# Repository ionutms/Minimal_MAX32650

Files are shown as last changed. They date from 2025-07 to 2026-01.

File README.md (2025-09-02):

# Minimal_MAX32650

## Overview

This repository contains a minimal KiCad design project for the Analog Devices MAX32650, an ultra-low-power microcontroller unit (MCU) designed for high-performance, battery-powered applications. It is part of the DARWIN family of MCUs, which are built to handle complex applications in the evolving Internet of Things (IoT) landscape.

## Disclaimer

> [!NOTE]
> This project is provided "as is" and without any warranty, express or implied. For more details, please see the [LICENSE](LICENSE) file.

## About the MAX32650

The MAX32650 from Analog Devices is an ultra-low-power microcontroller unit (MCU) designed for high-performance, battery-powered applications. It is part of the DARWIN family of MCUs, which are built to handle complex applications in the evolving Internet of Things (IoT) landscape.

Key features include:

- **Processor:** It uses an Arm® Cortex®-M4 processor with a Floating Point Unit (FPU) that can run at a core speed of 120MHz.
- **Memory:** The MCU is equipped with 3MB of internal Flash memory and 1MB of internal SRAM. It also supports memory scalability through multiple memory-expansion interfaces.
- **Power Consumption:** It is designed for low power consumption, with a rating of 104µW/MHz when executing from cache at 1.1V. It features five low-power modes to control the clock, peripherals, and voltage.
- **Peripherals and Interfaces:** The MAX32650 includes a variety of interfaces, such as a USB 2.0 Full-Speed Device Interface, a Micro-SD Card Interface, and up to 105 General-Purpose I/O (GPIO) pins. It also has a SmartDMA feature that performs complex background processing to reduce overall power consumption.
- **Secure Versions:** A secure version, the MAX32651, is available with a trust protection unit (TPU) that provides features like an AES engine, a secure bootloader, and on-the-fly data decryption.

## Project Structure

```
minimal_max32650/
├── minimal_max32650.kicad_sch       # Main schematic file
├── minimal_max32650.kicad_pcb       # PCB layout file
├── minimal_max32650.kicad_pro       # Project configuration file
├── fp-lib-table                     # Footprint library table
├── sym-lib-table                    # Symbol library table
├── project_jobs_set.kicad_jobset    # Project job settings
├── ibom.config.ini                  # Interactive BOM configuration
├── docs/                            # Documentation files
│   ├── pictures/                    # Images and photos
│   ├── schematics/                  # Schematic PDF exports
│   └── 3d_models/                   # 3D model files
└── KiCAD_Symbols_Generator/         # Submodule for symbol generation from CSV data
```

## Project Features

This design provides a minimal implementation of the MAX32650 with the following features:

- **Power Supply:**
  - VIN: +3.3V
- **Bill of Materials (BOM):**
  - Interactive HTML BOM (`ibom.html`) for easy component identification and sourcing.
- **Libraries:**
  - Comprehensive symbol and footprint libraries integrated as a submodule.
- **3D Model:**
  - Includes a 3D model of the board for better visualization.

## Getting Started

### Prerequisites

- [KiCad EDA](https://www.kicad.org/) version 9.0 or later installed on your system
- Git (for cloning the repository and submodule management)

### Opening the Project

1. **Clone the repository** (including submodules):
   ```bash
   git clone --recursive https://github.com/ionutms/Minimal_MAX32650.git
   ```
   
   If you've already cloned the repository without submodules, initialize them with:
   ```bash
   git submodule init
   git submodule update
   ```

2. **Open the project in KiCad**:
   - Launch KiCad
   - Click "Open Existing Project"
   - Navigate to the cloned repository folder
   - Select the `minimal_max32650.kicad_pro` file

3. **Explore the design**:
   - Open the schematic editor to view the circuit design
   - Open the PCB editor to view the board layout
   - Review the symbol and footprint libraries used in the design

### Project Files

- **Main schematic**: `minimal_max32650.kicad_sch` - Contains the primary circuit design with the MAX32650 and support components
- **PCB layout**: `minimal_max32650.kicad_pcb` - Physical board design file with proper component placement
- **Project configuration**: `minimal_max32650.kicad_pro` - KiCad project settings

## Dependencies

This project has the following dependencies:

### 1. KiCAD Symbols Generator

This repository uses [KiCAD_Symbols_Generator](https://github.com/ionutms/KiCAD_Symbols_Generator) as a submodule for custom symbol generation.

To initialize the submodule after cloning this repository:

```bash
git submodule update --init --recursive
```

### 2. 3D Models

This project requires the [3D_Models_Vault](https://github.com/ionutms/3D_Models_Vault) repository for 3D models.

#### Setup for KiCAD 9:

1. Clone the 3D models repository:
   ```bash
   git clone https://github.com/ionutms/3D_Models_Vault.git
   ```

2. In KiCAD 9, add an environment variable:
   - Variable name: `KICAD9_3D_MODELS_VAULT`
   - Variable value: Full path to where you cloned the 3D_Models_Vault repository

## Usage

After setting up the dependencies, open the project in KiCAD 9 to access all features including the 3D models.

## Symbol Generator Submodule

This project includes the KiCAD_Symbols_Generator as a submodule, which provides tools for generating KiCad symbols from CSV data files. For more information on using this tool, see the [KiCAD_Symbols_Generator documentation](minimal_max32650/KiCAD_Symbols_Generator/README.md).

## Documentation

The `docs` folder contains:
- Schematic PDF exports
- Images and photos of the design
- 3D model files (GLB and WRL formats)

## Visuals

The following images showcase the PCB design from different perspectives:

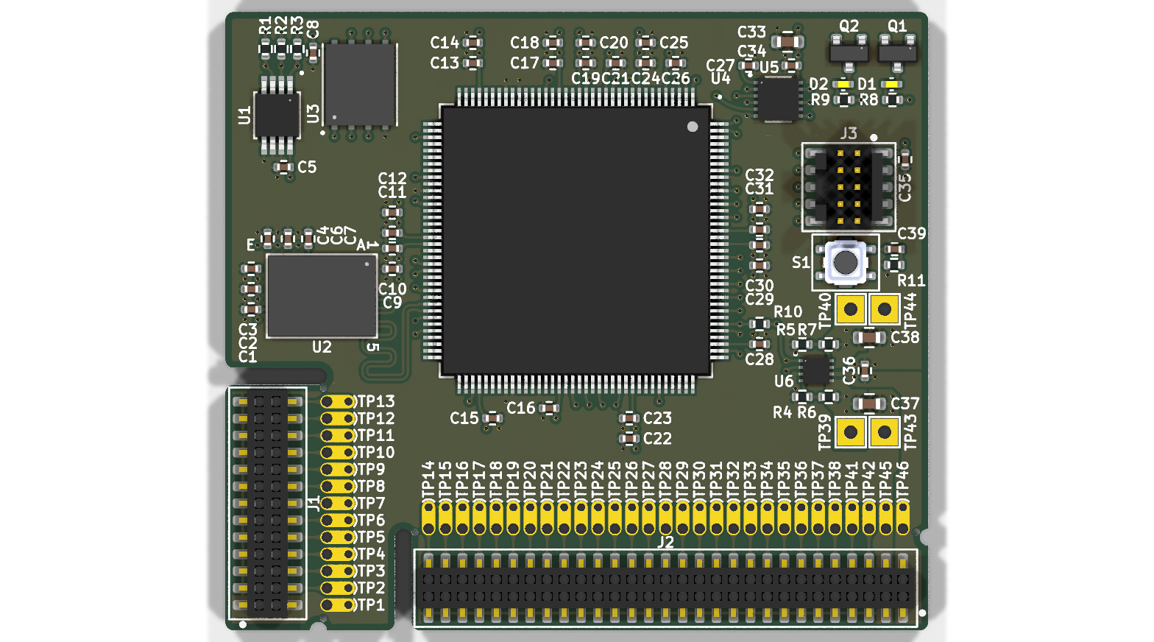
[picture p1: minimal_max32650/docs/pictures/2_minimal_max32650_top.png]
Top View

*Top View of the PCB*

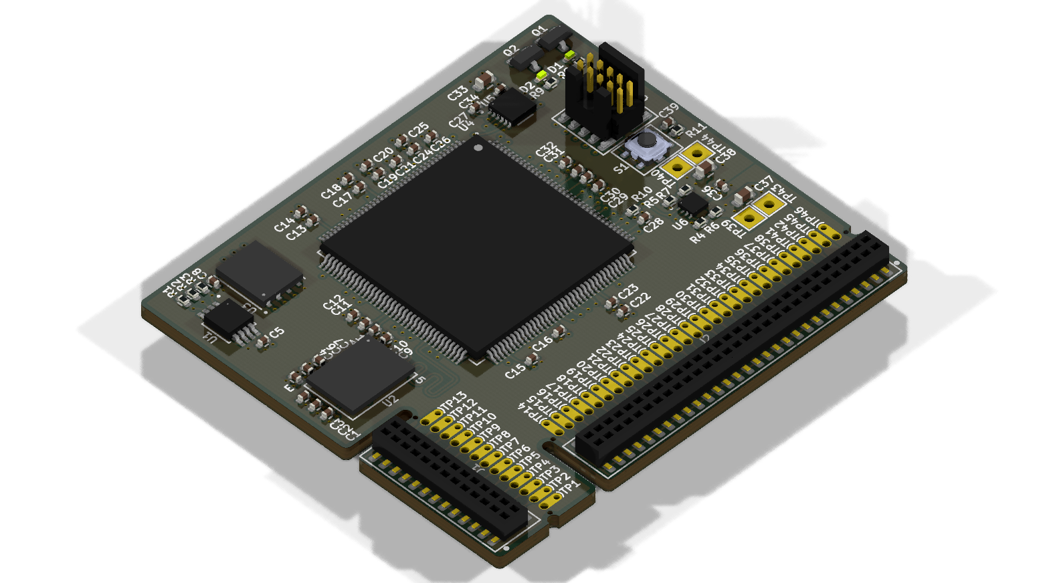
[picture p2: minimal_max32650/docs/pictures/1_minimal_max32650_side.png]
Side View

*Side View of the PCB*

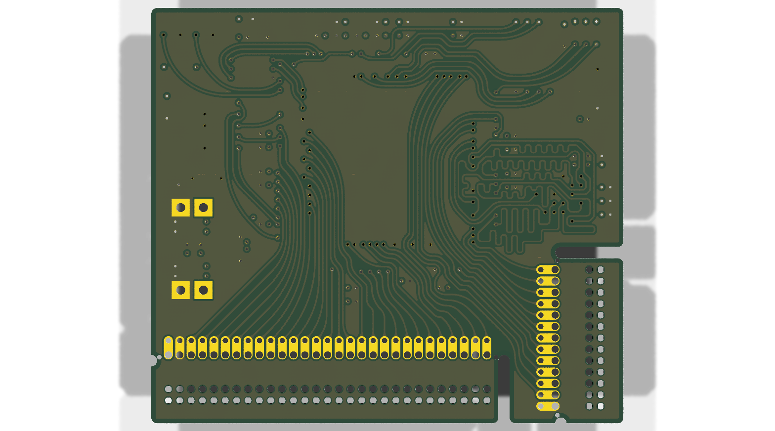
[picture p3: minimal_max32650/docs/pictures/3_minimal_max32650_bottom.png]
Bottom View

*Bottom View of the PCB*

## License

This project is licensed under the MIT License - see the [LICENSE](LICENSE) file for details.

## References

- [MAX32650 Datasheet](https://www.analog.com/media/en/technical-documentation/data-sheets/MAX32650-MAX32651.pdf)
- [KiCad EDA](https://www.kicad.org/)

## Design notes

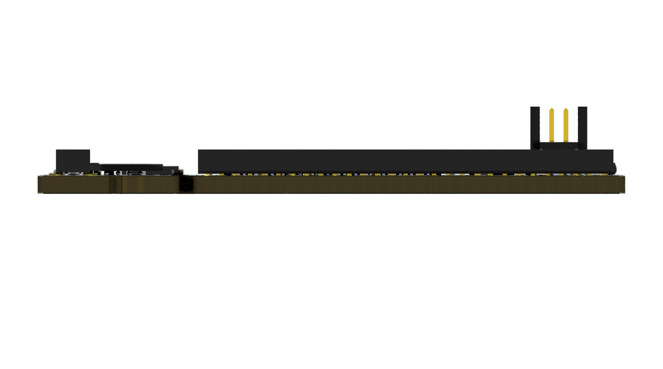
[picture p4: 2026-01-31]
minimal_max32650/docs/pictures/6_minimal_max32650_front.png

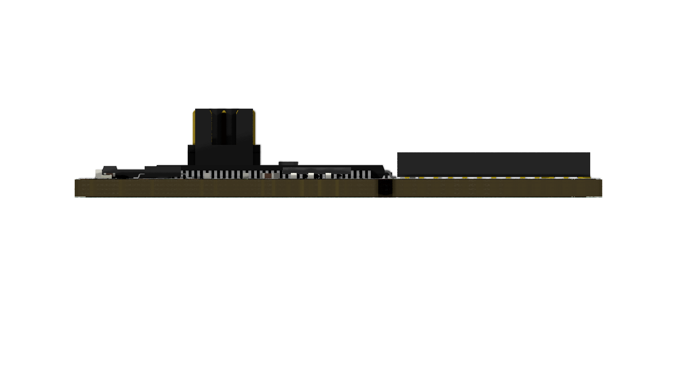
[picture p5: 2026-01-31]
minimal_max32650/docs/pictures/4_minimal_max32650_left.png

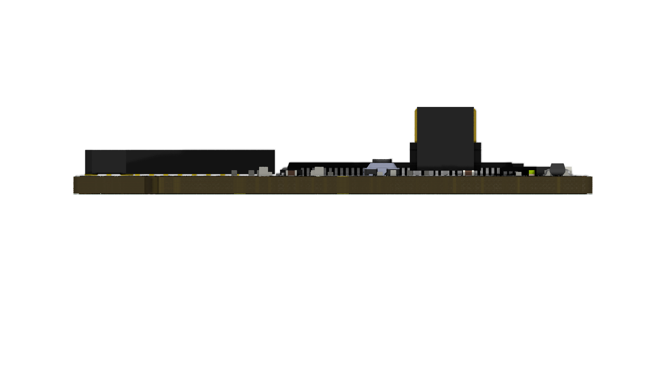
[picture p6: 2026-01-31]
minimal_max32650/docs/pictures/5_minimal_max32650_right.png

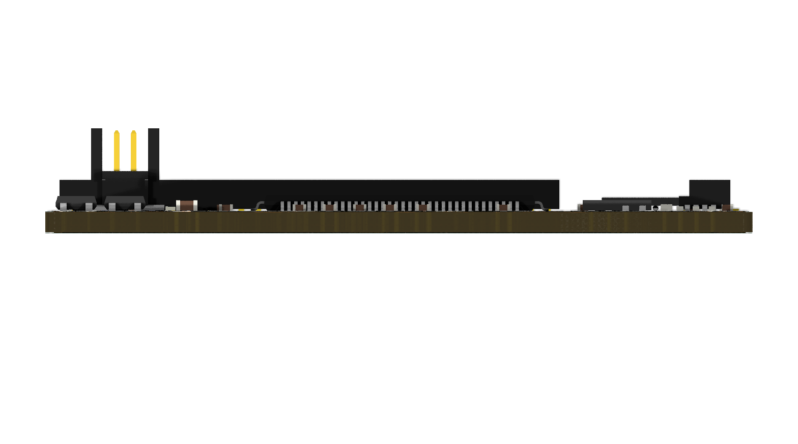
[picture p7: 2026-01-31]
minimal_max32650/docs/pictures/7_minimal_max32650_back.png

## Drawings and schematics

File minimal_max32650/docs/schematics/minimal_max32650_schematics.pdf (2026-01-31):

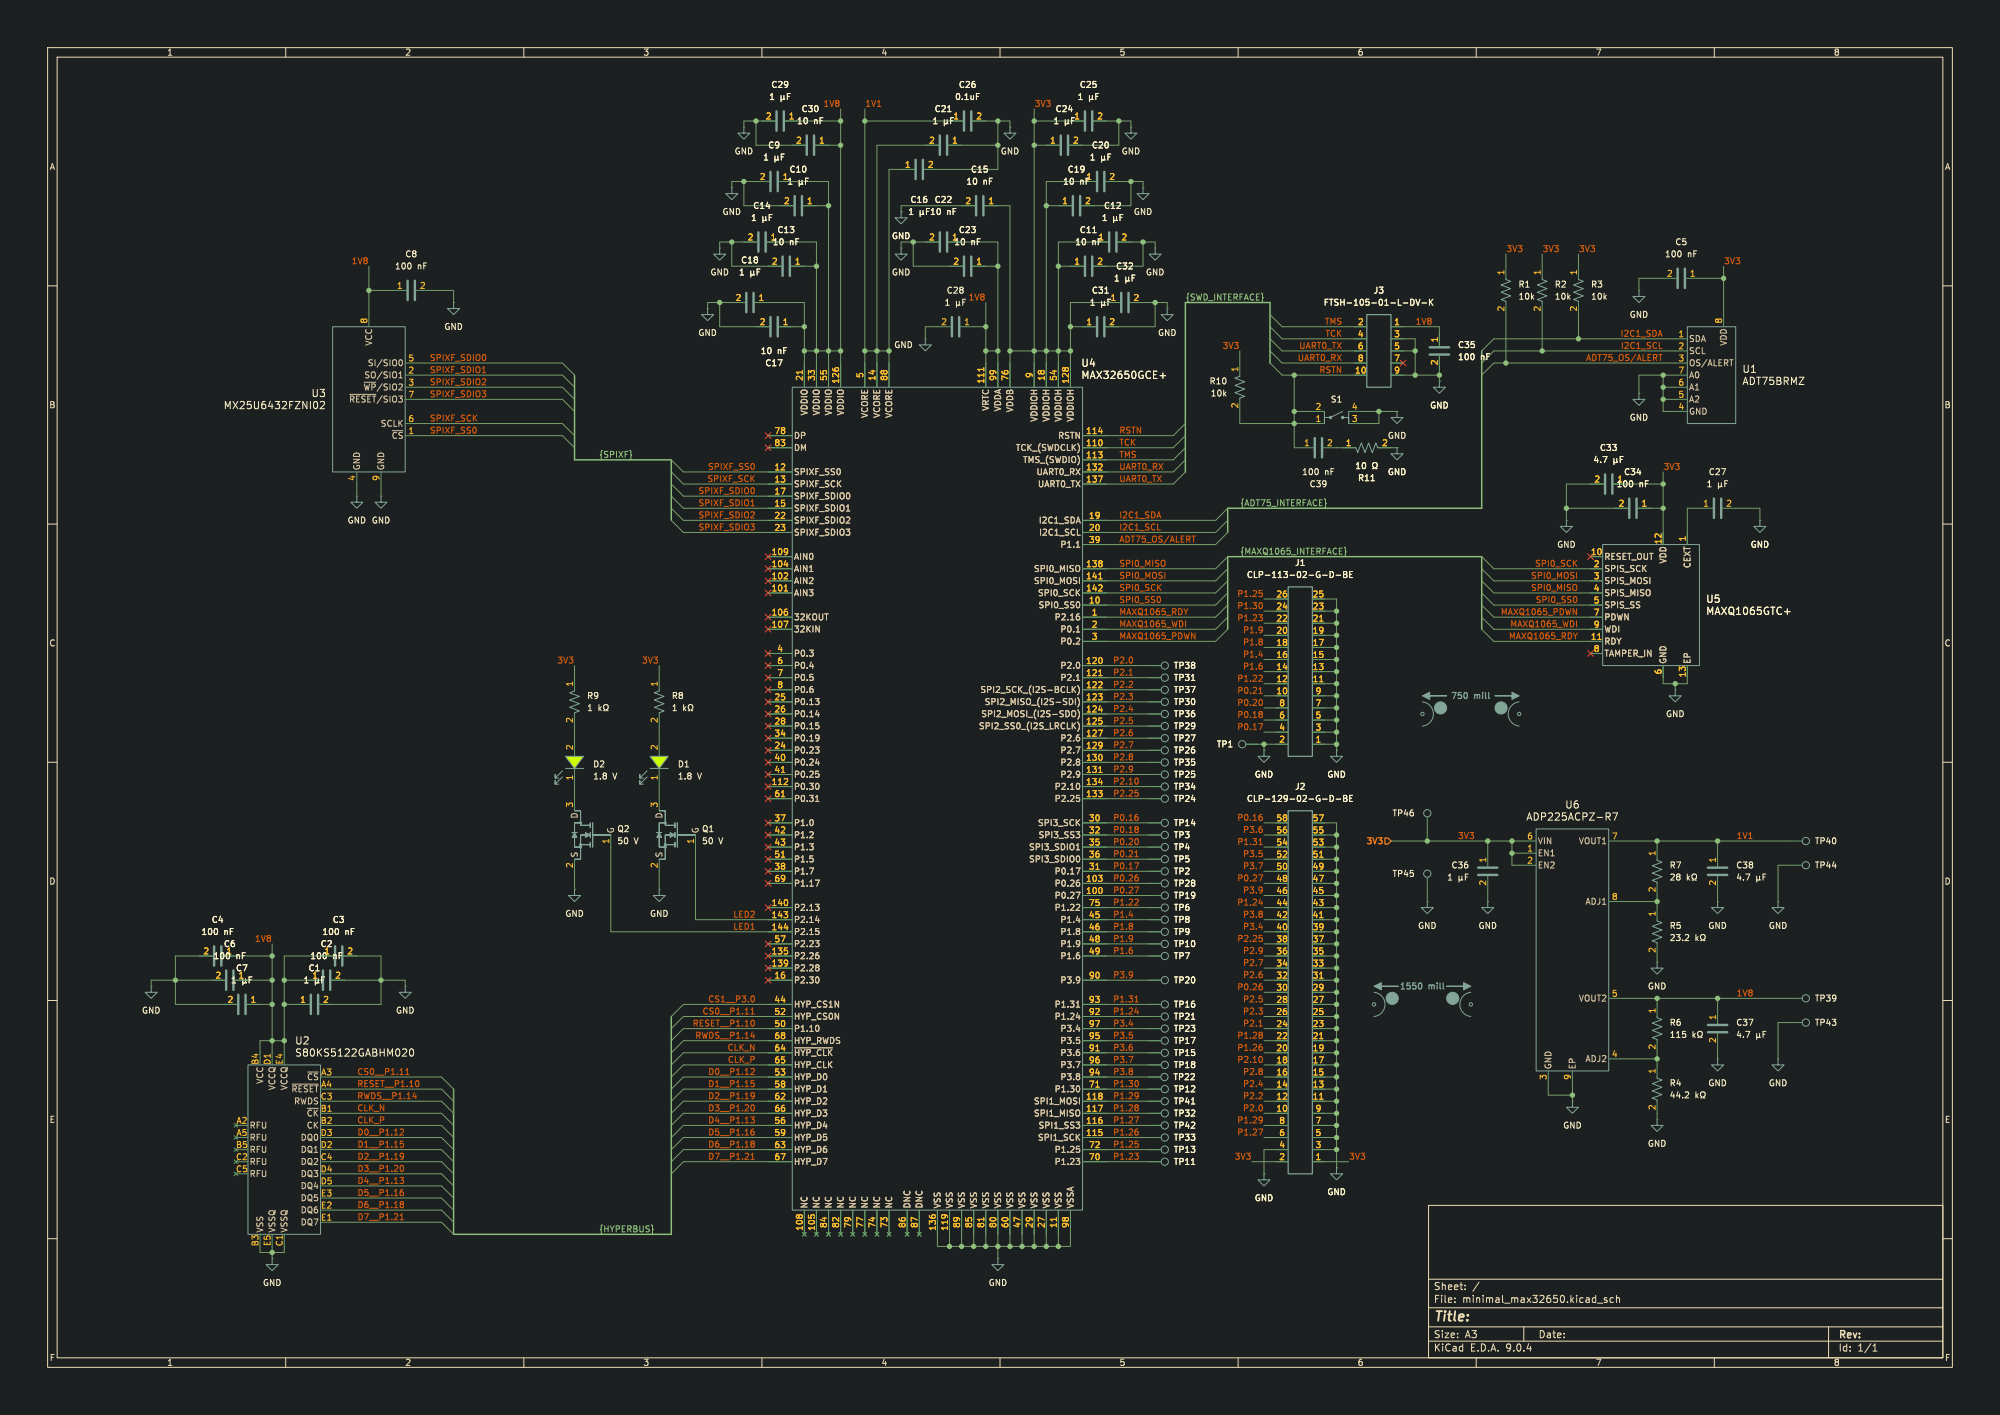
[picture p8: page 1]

9 SI/SIO0 5 SO/SIO1 2 SCLK 6 ~{WP}/SIO23 ~{RESET}/SIO37 ~{CS}1 U3 MX25U6432FZNI02

5 NC 77 VCORE 14 NC 74 VCORE 88 NC 73 DNC 86 DNC 87 VSS 136 VSS 119 VSS 89 VSS 85 VRTC 111 VSS 81 VDDA 99 VSS 80 VDDB 76 VSS 60 VSS 47 VDDIOH

9 VSS 29 VDDIOH 18 VSS 27 VDDIOH 54 VSS 11 VDDIOH 128 VSSA 98 RSTN 114 TCK_(SWDCLK) 110 TMS_(SWDIO) 113 UART0_RX 132 UART0_TX 137

Id: 1/1 Title: File: minimal_max32650.kicad_sch Sheet: /

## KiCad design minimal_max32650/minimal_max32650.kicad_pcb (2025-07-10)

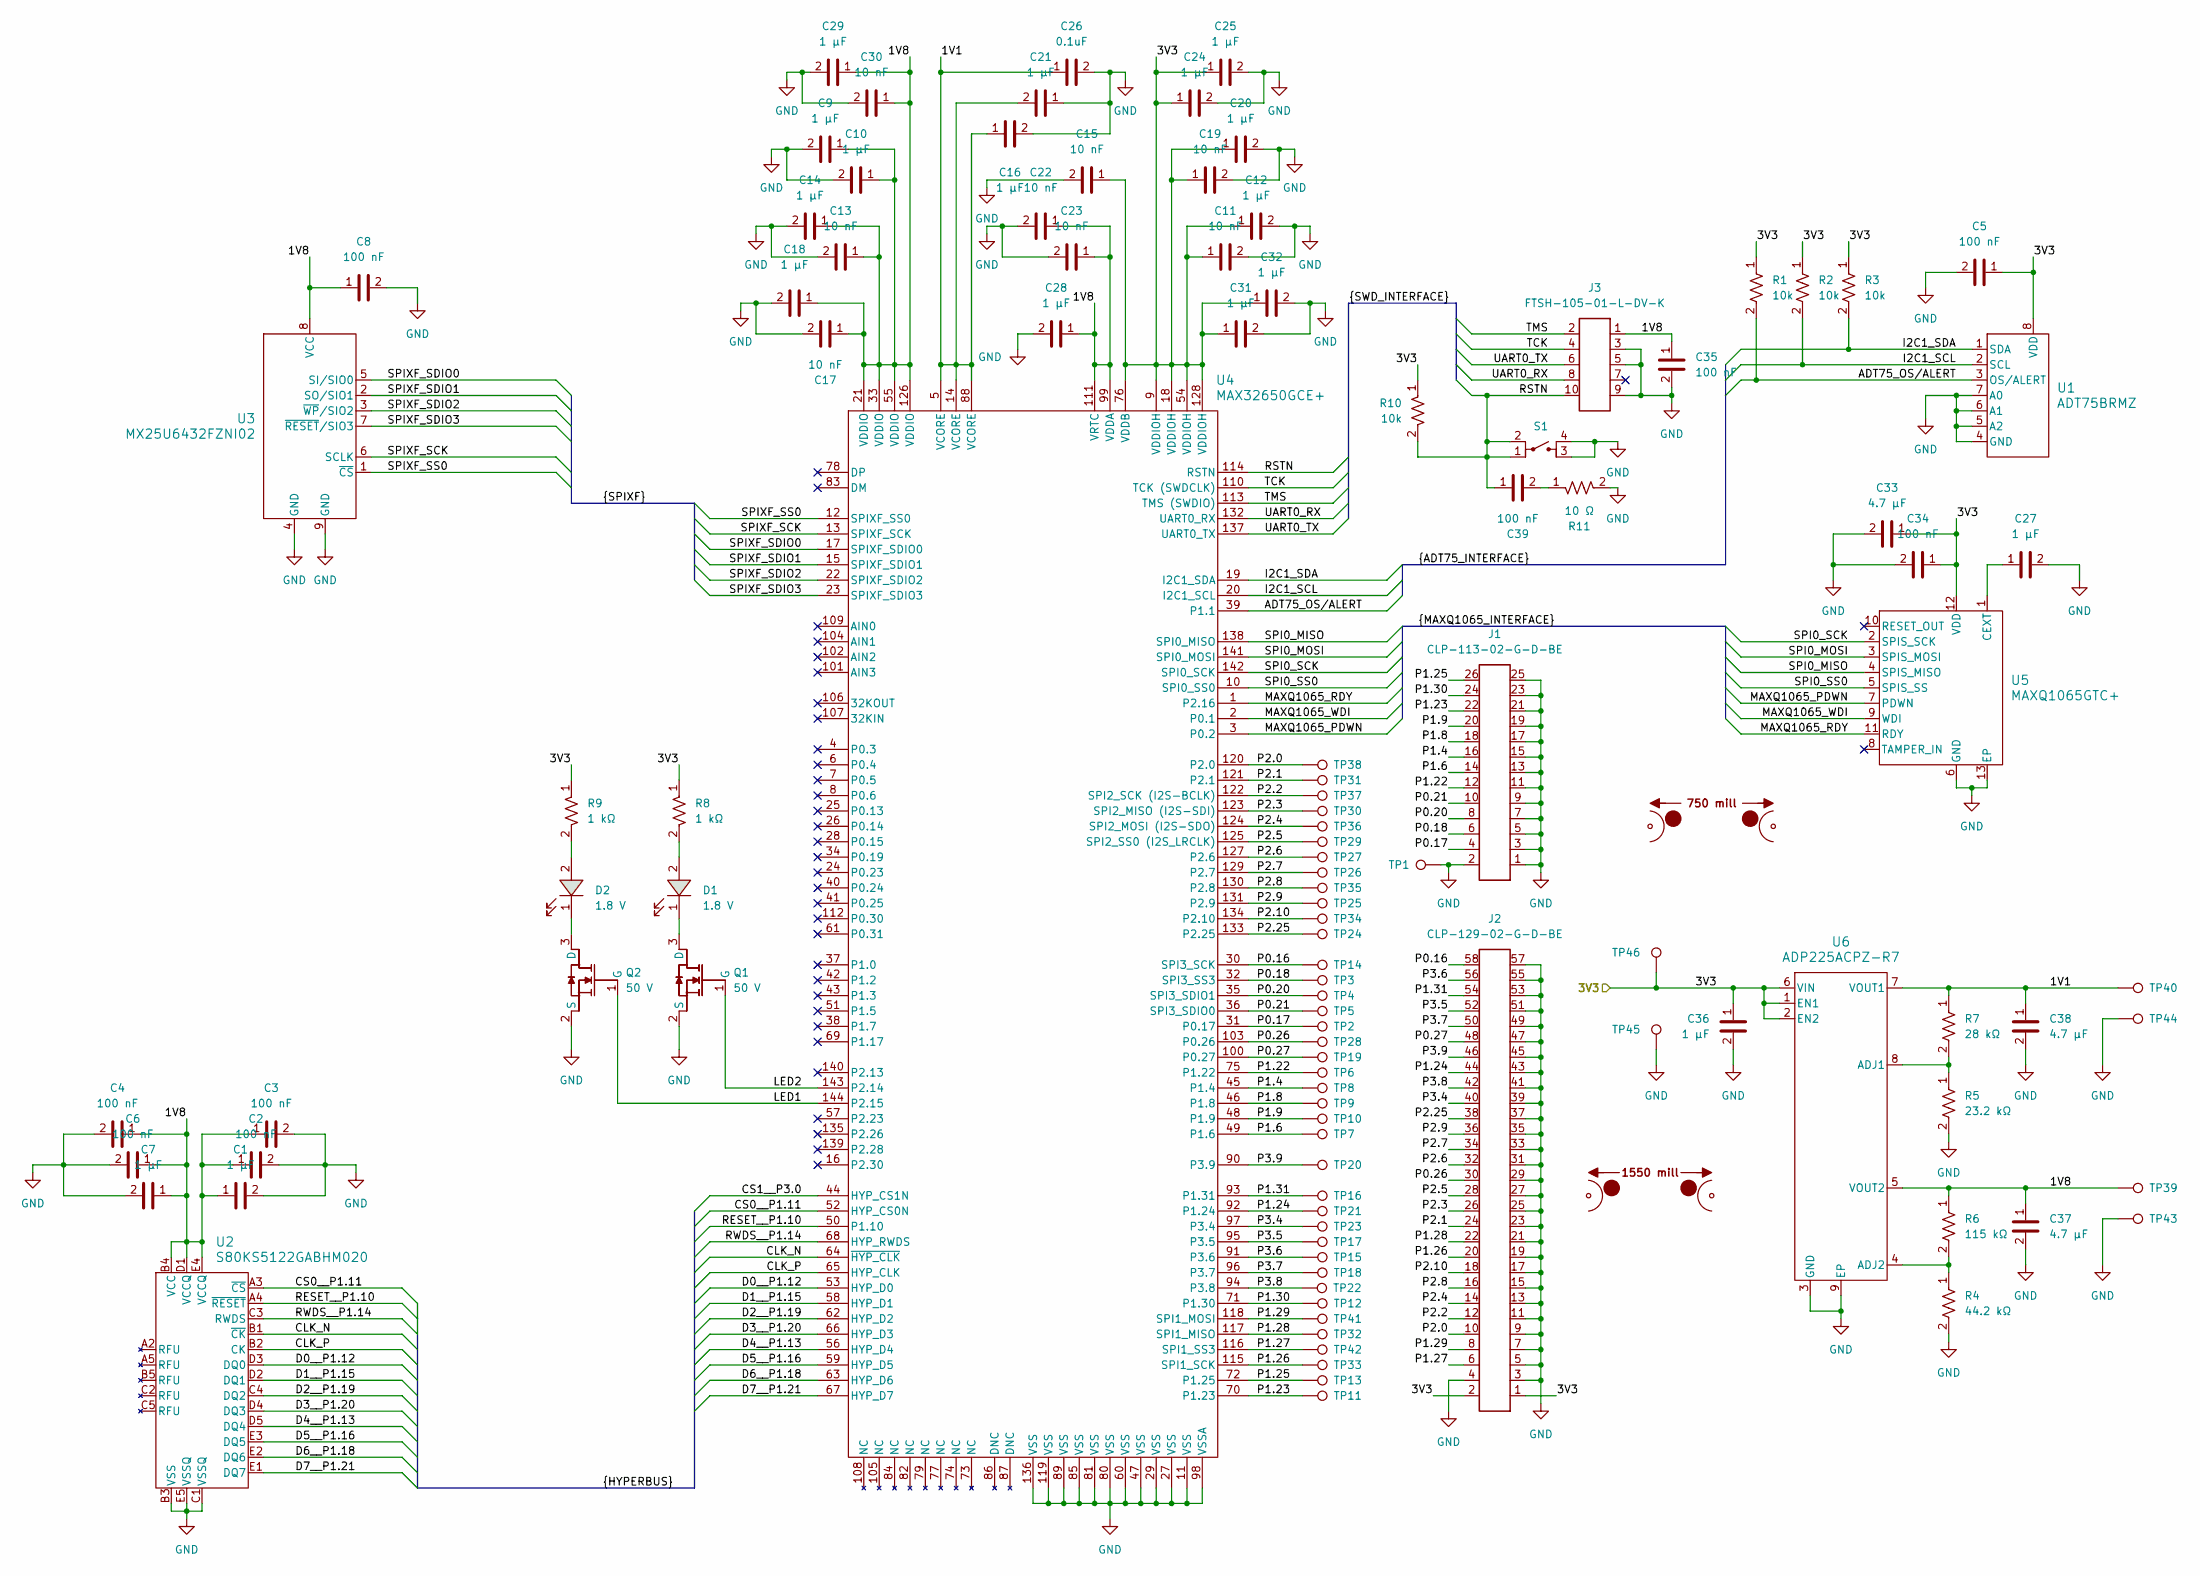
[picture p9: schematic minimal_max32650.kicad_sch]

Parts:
C1, C7, C9, C10, C12, C14, C16, C18, C20, C21, C24, C25, C27, C28, C29, C31, C32, C36: 1 µF; C_0402_1005Metric; Voltage Rating DC 16 VDC; Tolerance 10%; MPN C1005X6S1C105K050BC
C2, C3, C4, C5, C6, C8, C34, C35, C39: 100 nF; C_0402_1005Metric; Voltage Rating DC 50 VDC; Tolerance 10%; MPN GCM155R71H104KE02D
C11, C13, C15, C17, C19, C22, C23, C30: 10 nF; C_0402_1005Metric; Voltage Rating DC 100 VDC; Tolerance 10%; MPN C1005X7S2A103K050BB
C26: 0.1uF; C_0402_1005Metric; Voltage Rating DC 50 VDC; Tolerance 10%; MPN GCM155R71H104KE02D
C33, C37, C38: 4.7 µF; C_0603_1608Metric; Voltage Rating DC 10 VDC; Tolerance 10%; MPN C1608X7S1A475K080AC
D1, D2: 1.8 V; LED_GREEN_0402_1005Metric; MPN APHHS1005CGCK
J1: CLP-113-02-G-D-BE; Current Rating (A) 5.2; Voltage Rating (V) 300; MPN CLP-113-02-G-D-BE
J2: CLP-129-02-G-D-BE; Current Rating (A) 5.2; Voltage Rating (V) 300; MPN CLP-129-02-G-D-BE
J3: FTSH-105-01-L-DV-K; Current Rating (A) 5.2; Voltage Rating (V) 300; PARTREV H
MB1: mouse-bite-50mil-750mil
MB2: mouse-bite-50mil-1550mil
Q1, Q2: 50 V; SOT23-3; MPN BSS138-7-F
R1, R2, R3, R10: 10k; R_0402_1005Metric; Voltage Rating 50V; Tolerance 1%; MPN ERJ-2RKF1002X
R4: 44.2 kΩ; R_0402_1005Metric; Voltage Rating 50V; Tolerance 1%; MPN ERJ-2RKF4422X
R5: 23.2 kΩ; R_0402_1005Metric; Voltage Rating 50V; Tolerance 1%; MPN ERJ-2RKF2322X
R6: 115 kΩ; R_0402_1005Metric; Voltage Rating 50V; Tolerance 1%; MPN ERJ-2RKF1153X
R7: 28 kΩ; R_0402_1005Metric; Voltage Rating 50V; Tolerance 1%; MPN ERJ-2RKF2802X
R8, R9: 1 kΩ; R_0402_1005Metric; Voltage Rating 50V; Tolerance 1%; MPN ERJ-2RKF1001X
R11: 10 Ω; R_0402_1005Metric; Tolerance 1%; Voltage Rating 50V; MPN ERJ-2RKF10R0X
S1: TS21-34-035-BK-160-SMT-TR; TS21; MPN TS21-34-035-BK-160-SMT-TR
TP1, TP2, TP3, TP4, TP5, TP6, TP7, TP8, TP9, TP10, TP11, TP12, TP13, TP14, TP15, TP16, TP17, TP18, TP19, TP20, TP21, TP22, TP23, TP24, TP25, TP26, TP27, TP28, TP29, TP30, TP31, TP32, TP33, TP34, TP35, TP36, TP37, TP38, TP41, TP42, TP45, TP46: TestPoint; TestPoint_THTPad_Castelated
TP39, TP40, TP43, TP44: TestPoint; TestPoint_THTPad_2.0x2.0mm_Drill1.0mm
U1: ADT75BRMZ; RM_8_ADI; MPN ADT75BRMZ
U2: S80KS5122GABHM020; PG-BGA-24-801; MPN S80KS5122GABHM020
U3: MX25U6432FZNI02; WSON-8_6X5_MAC; MPN MX25U6432FZNI02
U4: MAX32650GCE+; 21-0087_C144&plus_1C_MXM; MPN MAX32650GCE+
U5: MAXQ1065GTC+; 21-0664_TD1233&plus_1C_MXM; MPN MAXQ1065GTC+
U6: ADP225ACPZ-R7; CP_8_10_ADI; MPN ADP225ACPZ-R7

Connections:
/1V1: C16.1, C21.2, C26.1, C38.1, R7.1, TP40.1, U4.5 (VCORE), U4.14 (VCORE), U4.88 (VCORE), U6.7 (VOUT1)
/1V8: C1.1, C2.1, C3.1, C4.1, C6.1, C7.1, C8.1, C9.1, C10.1, C13.1, C14.1, C17.1, C18.1, C22.1, C23.1, C28.1, C29.1, C30.1, C35.1, C37.1, J3.1, R6.1, TP39.1, U2.B4 (VCC), U2.D1 (VCCQ), U2.E4 (VCCQ), U3.8 (VCC), U4.21 (VDDIO), U4.33 (VDDIO), U4.55 (VDDIO), U4.99 (VDDA), U4.111 (VRTC), U4.126 (VDDIO), U6.5 (VOUT2)
/3V3: C5.1, C11.1, C12.1, C15.1, C19.1, C20.1, C24.1, C25.1, C31.1, C32.1, C33.1, C34.1, C36.1, J2.1, J2.2, R1.1, R2.1, R3.1, R8.1, R9.1, R10.1, TP46.1, U1.8 (VDD), U4.9 (VDDIOH), U4.18 (VDDIOH), U4.54 (VDDIOH), U4.76 (VDDB), U4.128 (VDDIOH), U5.12 (VDD), U6.1 (EN1), U6.2 (EN2), U6.6 (VIN)
/ADT75_OS/ALERT: R1.2, U1.3 (OS/ALERT), U4.39 (P1.1)
/CLK_N: U2.B1 (~CK), U4.64 (~HYP_CLK)
/CLK_P: U2.B2 (CK), U4.65 (HYP_CLK)
/CS0__P1.11: U2.A3 (~CS), U4.52 (HYP_CS0N)
/CS1__P3.0: U4.44 (HYP_CS1N)
/D0__P1.12: U2.D3 (DQ0), U4.53 (HYP_D0)
/D1__P1.15: U2.D2 (DQ1), U4.58 (HYP_D1)
/D2__P1.19: U2.C4 (DQ2), U4.62 (HYP_D2)
/D3__P1.20: U2.D4 (DQ3), U4.66 (HYP_D3)
/D4__P1.13: U2.D5 (DQ4), U4.56 (HYP_D4)
/D5__P1.16: U2.E3 (DQ5), U4.59 (HYP_D5)
/D6__P1.18: U2.E2 (DQ6), U4.63 (HYP_D6)
/D7__P1.21: U2.E1 (DQ7), U4.67 (HYP_D7)
/I2C1_SCL: R2.2, U1.2 (SCL), U4.20 (I2C1_SCL)
/I2C1_SDA: R3.2, U1.1 (SDA), U4.19 (I2C1_SDA)
/LED1: Q2.1 (G), U4.144 (P2.15)
/LED2: Q1.1 (G), U4.143 (P2.14)
/MAXQ1065_PDWN: U4.3 (P0.2), U5.7 (PDWN)
/MAXQ1065_RDY: U4.1 (P2.16), U5.11 (RDY)
/MAXQ1065_WDI: U4.2 (P0.1), U5.9 (WDI)
/P0.16: J2.58, TP14.1, U4.30 (SPI3_SCK)
/P0.17: J1.4, TP2.1, U4.31 (P0.17)
/P0.18: J1.6, TP3.1, U4.32 (SPI3_SS3)
/P0.20: J1.8, TP4.1, U4.35 (SPI3_SDIO1)
/P0.21: J1.10, TP5.1, U4.36 (SPI3_SDIO0)
/P0.26: J2.30, TP28.1, U4.103 (P0.26)
/P0.27: J2.48, TP19.1, U4.100 (P0.27)
/P1.4: J1.16, TP8.1, U4.45 (P1.4)
/P1.6: J1.14, TP7.1, U4.49 (P1.6)
/P1.8: J1.18, TP9.1, U4.46 (P1.8)
/P1.9: J1.20, TP10.1, U4.48 (P1.9)
/P1.22: J1.12, TP6.1, U4.75 (P1.22)
/P1.23: J1.22, TP11.1, U4.70 (P1.23)
/P1.24: J2.44, TP21.1, U4.92 (P1.24)
/P1.25: J1.26, TP13.1, U4.72 (P1.25)
/P1.26: J2.20, TP33.1, U4.115 (SPI1_SCK)
/P1.27: J2.6, TP42.1, U4.116 (SPI1_SS3)
/P1.28: J2.22, TP32.1, U4.117 (SPI1_MISO)
/P1.29: J2.8, TP41.1, U4.118 (SPI1_MOSI)
/P1.30: J1.24, TP12.1, U4.71 (P1.30)
/P1.31: J2.54, TP16.1, U4.93 (P1.31)
/P2.0: J2.10, TP38.1, U4.120 (P2.0)
/P2.1: J2.24, TP31.1, U4.121 (P2.1)
/P2.2: J2.12, TP37.1, U4.122 (SPI2_SCK (I2S-BCLK))
/P2.3: J2.26, TP30.1, U4.123 (SPI2_MISO (I2S-SDI))
/P2.4: J2.14, TP36.1, U4.124 (SPI2_MOSI (I2S-SDO))
/P2.5: J2.28, TP29.1, U4.125 (SPI2_SS0 (I2S_LRCLK))
/P2.6: J2.32, TP27.1, U4.127 (P2.6)
/P2.7: J2.34, TP26.1, U4.129 (P2.7)
/P2.8: J2.16, TP35.1, U4.130 (P2.8)
/P2.9: J2.36, TP25.1, U4.131 (P2.9)
/P2.10: J2.18, TP34.1, U4.134 (P2.10)
/P2.25: J2.38, TP24.1, U4.133 (P2.25)
/P3.4: J2.40, TP23.1, U4.97 (P3.4)
/P3.5: J2.52, TP17.1, U4.95 (P3.5)
/P3.6: J2.56, TP15.1, U4.91 (P3.6)
/P3.7: J2.50, TP18.1, U4.96 (P3.7)
/P3.8: J2.42, TP22.1, U4.94 (P3.8)
/P3.9: J2.46, TP20.1, U4.90 (P3.9)
/RESET__P1.10: U2.A4 (~RESET), U4.50 (P1.10)
/RSTN: C39.1, J3.10, R10.2, S1.1, S1.2, U4.114 (RSTN)
/RWDS__P1.14: U2.C3 (RWDS), U4.68 (HYP_RWDS)
/SPI0_MISO: U4.138 (SPI0_MISO), U5.4 (SPIS_MISO)
/SPI0_MOSI: U4.141 (SPI0_MOSI), U5.3 (SPIS_MOSI)
/SPI0_SCK: U4.142 (SPI0_SCK), U5.2 (SPIS_SCK)
/SPI0_SS0: U4.10 (SPI0_SS0), U5.5 (SPIS_SS)
/SPIXF_SCK: U3.6 (SCLK), U4.13 (SPIXF_SCK)
/SPIXF_SDIO0: U3.5 (SI/SIO0), U4.17 (SPIXF_SDIO0)
/SPIXF_SDIO1: U3.2 (SO/SIO1), U4.15 (SPIXF_SDIO1)
/SPIXF_SDIO2: U3.3 (~WP/SIO2), U4.22 (SPIXF_SDIO2)
/SPIXF_SDIO3: U3.7 (~RESET/SIO3), U4.23 (SPIXF_SDIO3)
/SPIXF_SS0: U3.1 (~CS), U4.12 (SPIXF_SS0)
/TCK: J3.4, U4.110 (TCK (SWDCLK))
/TMS: J3.2, U4.113 (TMS (SWDIO))
/UART0_RX: J3.8, U4.132 (UART0_RX)
/UART0_TX: J3.6, U4.137 (UART0_TX)
GND: C1.2, C2.2, C3.2, C4.2, C5.2, C6.2, C7.2, C8.2, C9.2, C10.2, C11.2, C12.2, C13.2, C14.2, C15.2, C16.2, C17.2, C18.2, C19.2, C20.2, C21.1, C22.2, C23.2, C24.2, C25.2, C26.2, C27.2, C28.2, C29.2, C30.2, C31.2, C32.2, C33.2, C34.2, C35.2, C36.2, C37.2, C38.2, J1.1, J1.2, J1.3, J1.5, J1.7, J1.9, J1.11, J1.13, J1.15, J1.17, J1.19, J1.21, J1.23, J1.25, J2.3, J2.4, J2.5, J2.7, J2.9, J2.11, J2.13, J2.15, J2.17, J2.19, J2.21, J2.23, J2.25, J2.27, J2.29, J2.31, J2.33, J2.35, J2.37, J2.39, J2.41, J2.43, J2.45, J2.47, J2.49, J2.51, J2.53, J2.55, J2.57, J3.3, J3.5, J3.9, Q1.2 (S), Q2.2 (S), R4.2, R5.2, R11.2, S1.3, S1.4, TP1.1, TP43.1, TP44.1, TP45.1, U1.4 (GND), U1.5 (A2), U1.6 (A1), U1.7 (A0), U2.B3 (VSS), U2.C1 (VSSQ), U2.E5 (VSSQ), U3.4 (GND), U3.9 (GND), U4.11 (VSS), U4.27 (VSS), U4.29 (VSS), U4.47 (VSS), U4.60 (VSS), U4.80 (VSS), U4.81 (VSS), U4.85 (VSS), U4.89 (VSS), U4.98 (VSSA), U4.119 (VSS), U4.136 (VSS), U5.6 (GND), U5.13 (EP), U6.3 (GND), U6.9 (EP)
unnamed: C39.2, R11.1
unnamed: D1.2, R8.2
unnamed: D2.2, R9.2
unnamed: D1.1, Q1.3 (D)
unnamed: D2.1, Q2.3 (D)
unnamed: C27.1, U5.1 (CEXT)
unnamed: R5.1, R7.2, U6.8 (ADJ1)
unnamed: R4.1, R6.2, U6.4 (ADJ2)

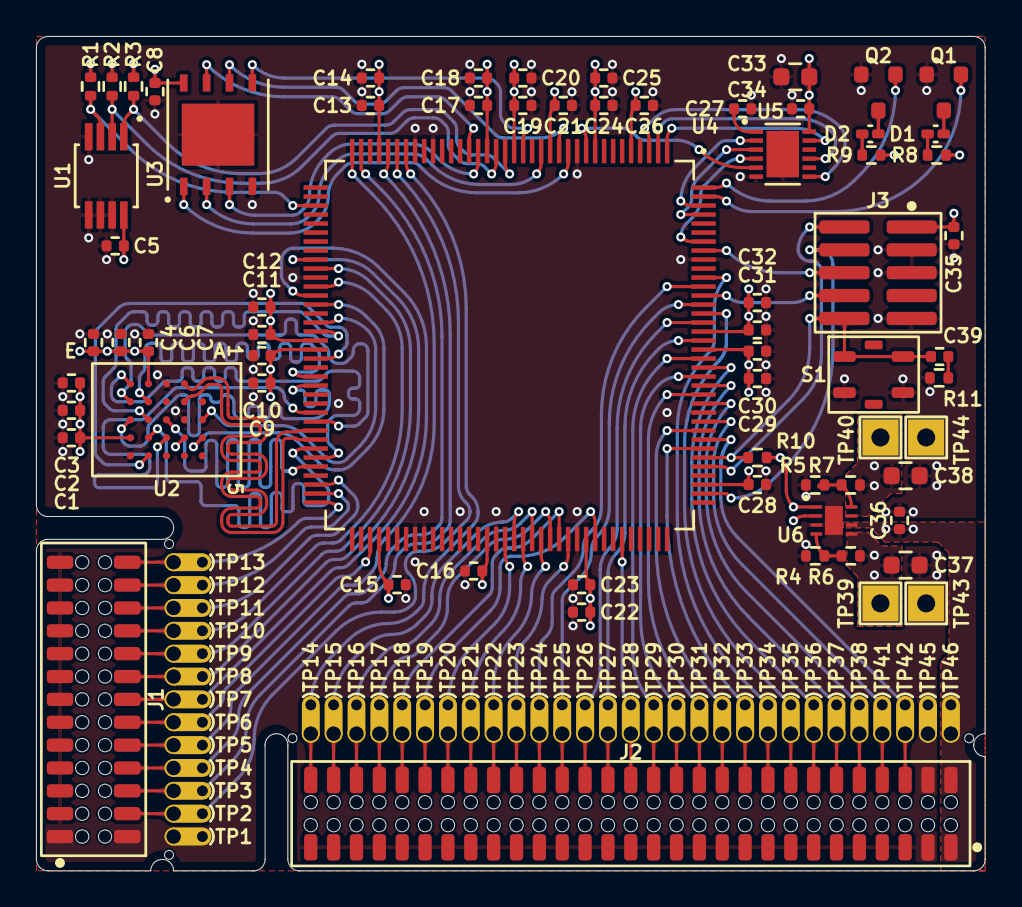
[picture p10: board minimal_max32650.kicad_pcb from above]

Board: 4 copper layers, 52.7 x 46.4 mm, 112 parts (0 on the bottom side), 87 nets.

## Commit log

2025-03-25 Add initial KiCad project files for minimal_max32650
    [minimal_max32650.kicad_pcb, minimal_max32650.kicad_sch]
2025-03-25 Add submodule for KiCAD Symbols Generator
2025-03-25 Add footprint and symbol library tables for KiCad project
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2025-03-25 Add job set configuration for KiCad project rendering and exporting
2025-03-26 development backup
    [minimal_max32650.kicad_pcb, minimal_max32650.kicad_sch]
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2025-03-27 Add Macronix footprints and symbols to KiCad library tables
2025-03-27 Add SPI interface color mappings to KiCad project
    [minimal_max32650.kicad_pcb, minimal_max32650.kicad_sch]
2025-03-27 Update 3D models and add schematic export job to KiCad project
2025-03-29 Add Infineon footprints and symbols to KiCad library tables
2025-03-31 Update 3D models, images, and schematics for minimal_max32650 documentation
2025-04-01 Update generate_kicad_jobs.yml to enhance project file verification and streamline schematic generation
2025-04-01 Rename job to generate KiCad Schematic PDFs and implement multiple approaches for PDF generation with improved error handling and permissions management
2025-04-01 Update schematic outputs [skip ci]
2025-04-01 Remove verbose flag from Docker command for PDF schematic generation
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2025-04-01 Refactor PDF generation workflow to improve file handling and add checks for generated schematic files
2025-04-01 Update GitHub Actions workflow to generate schematic PDFs with a specified theme
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2025-04-01 Enhance GitHub Actions workflow to test multiple themes for schematic PDF generation and implement fallback options
2025-04-01 Generate schematic PDFs with support for multiple themes and fallback options
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2025-04-01 Add debugging steps for KiCad CLI in PDF schematic generation workflow
2025-04-01 Enhance GitHub Actions workflow to generate schematic PDFs with specified themes and conditional commits
2025-04-01 Update GitHub Actions workflow to generate schematic PDFs with specified theme and improved logging
2025-04-01 Update KiCad Docker image version to 9.0.1 in workflow
2025-04-01 Update KiCad Docker image version to 9.0.0-amd64 in workflow
2025-04-01 Update KiCad Docker image version to 8.0 in workflow
2025-04-01 Update KiCad Docker image version to 9.0 in workflow
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2025-04-01 Update KiCad Docker image to nightly and change PDF export theme to gruvbox
2025-04-01 Add support for generating schematic PDFs with Gruvbox and default themes
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2025-04-01 Refactor KiCad job workflow to generate documentation, including schematic PDFs and PCB renders
2025-04-01 Generate the latest KiCad documentation (schematics and PCB renders)
2025-04-01 Fix formatting in KiCad job workflow for consistent command syntax
2025-04-01 Remove rotation option from PCB render command in KiCad job workflow
2025-04-01 Comment out push trigger for KiCad documentation generation workflow
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2025-04-14 Enable push trigger for KiCad documentation generation and update Docker image to custom version
2025-04-14 Update branch trigger for KiCad documentation generation workflow
2025-04-16 Update workflow to improve KiCad documentation generation process
2025-04-17 Enhance PCB rendering options in KiCad documentation generation workflow
2025-04-17 Refactor PCB rendering command for improved readability and maintainability
2025-04-17 Update Docker image version for KiCad documentation generation
2025-04-17 test workflow render
    [minimal_max32650.kicad_pcb, minimal_max32650.kicad_sch]
2025-04-17 test workflow render 2
    [minimal_max32650.kicad_pcb, minimal_max32650.kicad_sch]
2025-04-17 Refactor Docker command in workflow to improve 3D models handling and permissions for PCB rendering
2025-04-17 Update KiCad documentation (schematics and PCB renders) from output_generation branch
2025-04-17 Refactor output generation workflow to consolidate directory creation and improve file handling for generated KiCad documentation
2025-04-17 Refactor KiCad documentation generation workflow to improve file handling and streamline output verification
2025-04-17 Refactor file handling in KiCad documentation workflow to improve clarity and ensure proper restoration of generated files
2025-04-17 Fix missing conditional closure in KiCad documentation output commit step
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2025-04-17 Refactor KiCad project file verification step to improve clarity and output handling
2025-04-17 Reduce artifact retention period to 1 day in KiCad documentation workflow
2025-04-18 Add KiCad configuration file and enhance documentation generation workflow
2025-04-25 Refactor KiCad configuration handling and update documentation generation workflow
2025-04-25 Remove obsolete schematic and image files for the MAX32650 project
2025-04-25 Update KiCad documentation for minimal_max32650 (schematics and PCB renders)
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2025-05-24 Add GitHub Actions workflow to generate KiCad 3D models
2025-05-24 Enhance GitHub Actions workflows to support repository dispatch for KiCad 3D models and documentation generation
2025-05-24 Refactor KiCad workflow to simplify project file discovery and remove repository dispatch trigger
2025-05-24 Change solder mask color from Green to Blue for top and bottom layers
    [minimal_max32650.kicad_pcb]
2025-08-29 Update KiCad Docker image to V1.1 and add Interactive HTML BOM generation
2025-10-05 chore: update workflows and kicad config from central repository
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
